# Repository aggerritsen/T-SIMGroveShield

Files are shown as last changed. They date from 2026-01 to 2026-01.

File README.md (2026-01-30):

# T-SIM Grove shield (ESP32 / ESP32-S3)

This repository contains a **clean, deterministic UART/I2C/GPIO baseline** used to validate reliable communication between **LilyGO T-SIM boards** and other boards using a generic T-SIM Grove Shield. This shield also provides a male header connector for the XIAO slot of the Seeed Grove Vision AI V2 board.

The focus of this development is **transport correctness**, not application logic.
It provides a proven foundation for later integration of camera frames, AI inference data, or other high-volume payloads and the pilot of actuators like relays, DC or stepper motors and other I2C perhiphials development board. 

This development includes a UART stub for testing, build on a XIAO ESP32-S3. This board can be used with the Grove Shield for XIAO, linking both shields with a Grove cable. 

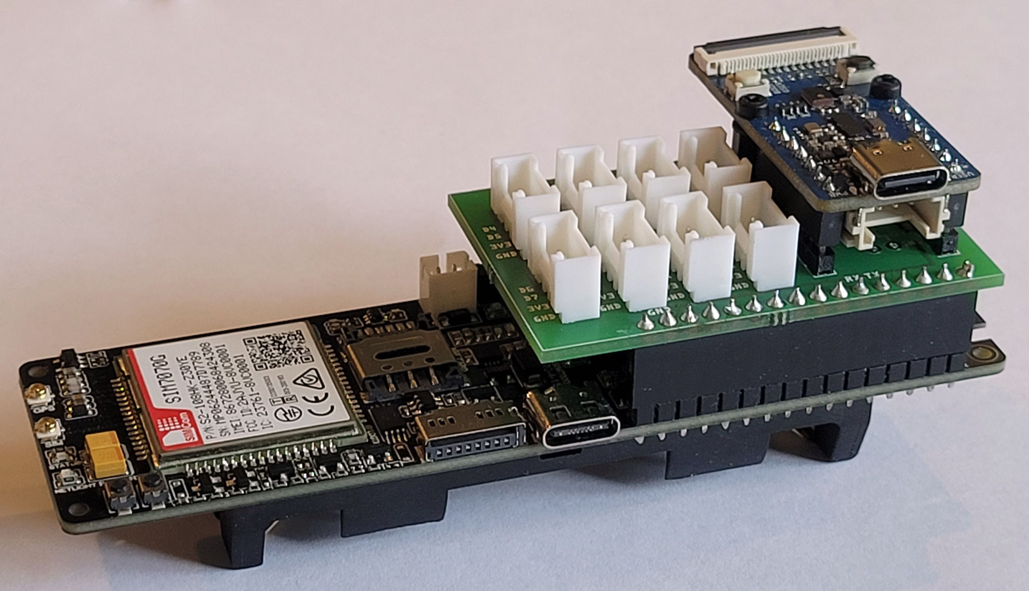
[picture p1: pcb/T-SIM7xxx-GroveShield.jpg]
PCB Grove Extension shield


## Printer Circuit Board (PCB)
A Fritzing file (fzz) is available to order the PCB at manufactors at choice.

Example shield:
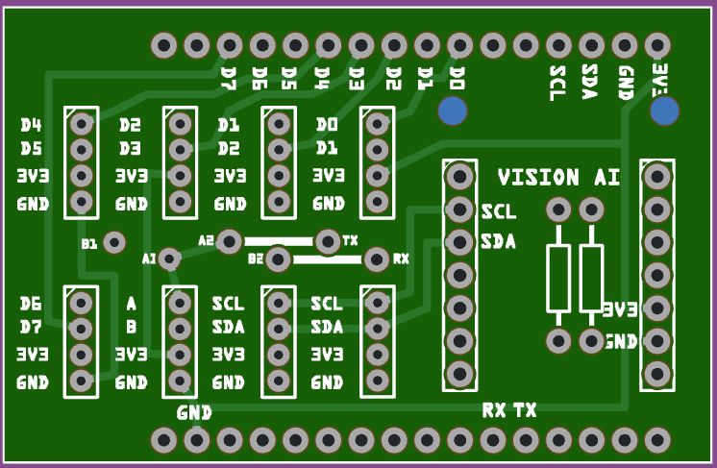
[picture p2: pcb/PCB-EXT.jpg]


## TX/RX wiring (Rev. B)
The TX and RX pins of UART Grove connector T-SIM Grove shield can be wired at choice with wire links.
| Config | Wires  | Pin 1 (A) | Pin 2 (B) |
|-----|-----|----|----|
|  1  | A1 -> TX, B1 -> RX | TX | RX |
|  2  | A2 -> RX, B2 -> TX | RX | TX | 

The wiring Pin1-TX, Pin2-RX (first configuration) is complementary to the cable wiring to the Grove Shield for XIAO (as shown in the picture) 

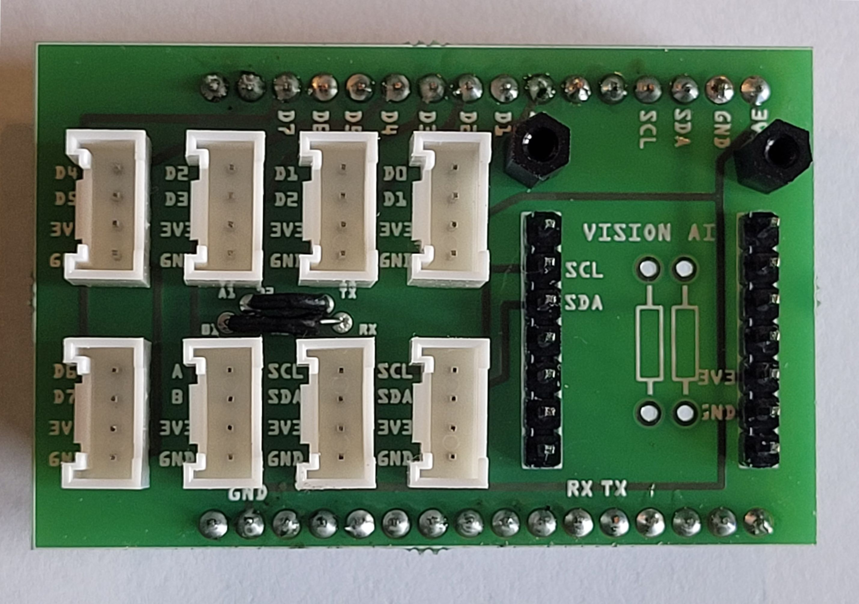
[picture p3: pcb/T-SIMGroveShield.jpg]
PCB Grove Extension shield


*The image shows earlier version with different UART wire bridges.*

---

## Goals of This Development

This project exists to answer these questions conclusively:

* Are pins wired correctly?
* Is high-speed UART stable (921600 baud) and I2C (400000 Hz)?
* Is the use of output GPIO consistent for all boards?
* Can we use generic shield (e.g. Grove, Relais, Motor driver) for all boards

---

* All boards use **HardwareSerial(1)** (UART1), leaving UART0 vor Serial communication
* All boards use **I2C-1 **, leaving I2C-0 for internal communication
* USB Serial is used **only for logging**
* The transport implementation is **identical across all boards**

---

## Supported Boards (current & verified)

| Board | MCU | Status |
| --- | --- | --- |
| XIAO ESP32-S3 | ESP32-S3 | ✅ Verified |
| T-SIM7080G-S3 | ESP32-S3 | ✅ Verified |
| T-SIM7070 | ESP32 | ✅ Verified |
| T-SIM7000G | ESP32 | ✅ Verified |
| T-SIM7600 | ESP32 / S3 | 🔜 Planned |
| T-SIM7670G | ESP32 / S3 | 🔜 Planned |

All verified boards are running **the same transport codebase**, differentiated only by PlatformIO environment configuration (pins, USB mode).

---

## Pin Configuration

### T-SIM7080G-S3 (ESP32-S3)

| Signal | GPIO | Notes |
| --- | --- | ----- |
| 3v3 | ------ | (P1.1) |
| GND | ------ | (P1.2) |
| SDA | GPIO16 | I2C-1 (P1.3) |
| SCL | GPIO17 | I2C-1 (P1.4) |
| TX  | GPIO43 | UART1 TX (P2.5)  |
| RX  | GPIO44 | UART1 RX (P2.6)  |
| D0 | GPIO03 | ----- |
| D1 | GPIO46 | *to be confirmed* |
| D2 | GPIO09 | ----- |
| D3 | GPIO10 | ----- |
| D4 | GPIO11 | ----- |
| D5 | GPIO12 | ----- |
| D6 | GPIO13 | ----- |
| D7 | GPIO14 | ----- |

### / T-SIM7000G / T-SIM7070 / T-SIM7600 / T-SIM7670G (ESP32 classic)

| Signal | GPIO | Notes |
| --- | --- | --- |
| 3v3 | ------ | (P1.1) |
| GND | ------ | (P1.2) |
| SDA | GPIO32 | I2C-1 (P1.3) |
| SCL | GPIO33 | I2C-1 (P1.4) |
| TX  | GPIO22 | UART1 TX (P2.5) |
| RX  | GPIO21 | UART1 RX (P2.6) |
| D0 | GPIO26 | ----- |
| D1 | GPIO25 | ----- |
| D2 | GPIO27 | ----- |
| D3 | GPIO04 | ----- |
| D4 | GPIO02 | ----- |
| D5 | GPIO15 | ----- |
| D6 | GPIO14 | ----- |
| D7 | GPIO13 | ----- |

**Important:**

* TX ↔ RX must be crossed
* GND must be shared
* Baud: 921600, 8N1 

---

## Architecture Overview for UART stub

```
+-------------------+        UART1 (921600 baud)        +---------------------+
| XIAO ESP32-S3     |  <----------------------------> | T-SIM (7080 / 7070 / |
| (Sender / Master) |                                  | 7000 Peer)          |
+-------------------+                                  +---------------------+
        |                                                             |
        | USB Serial (logs)                                           | USB Serial (logs)
        v                                                             v
   PlatformIO Monitor                                           PlatformIO Monitor
```

---

## Transport Protocol

The transport uses a **simple, explicit frame protocol**.

### Frame Format (wire-level)

```
FRAME <id> <len> <crc>
<payload>
END
```

### Fields

| Field | Meaning |
| --- | --- |
| `id` | Monotonic frame ID (uint32) |
| `len` | Exact payload length in bytes |
| `crc` | CRC32 (little-endian, hex) |
| `payload` | Message body |

The CRC is calculated **only over the payload**.

---

## Payload

In this baseline, the payload is **JSON text**, chosen for visibility:

```json
{
  "type": "sample",
  "frame": 7,
  "ts_ms": 16596,
  "msg": "Hello from XIAO UART1"
}
```

The transport is **payload-agnostic**. Binary data can replace JSON later without changing the protocol.

---

## CRC Handling

* Algorithm: **CRC32 little-endian**
* Implementation: `esp_crc32_le()` (ESP32 ROM)

A frame is rejected if:

* Payload length mismatches `len`
* Payload length exceeds safety limit
* CRC does not match

Rejected frames trigger a **NACK**.

---

## ACK / NACK Flow Control

### Normal flow

1. Sender transmits frame `N`
2. Receiver validates payload
3. Receiver replies:

```
ACK N
```

4. Sender advances to frame `N+1`

### Error flow

If validation fails:

```
NACK N
```

Sender resends **the same cached frame**.

### Timeout recovery

If no ACK or NACK is received within **5 seconds**:

* Sender automatically resends
* Frame ID does **not** advance

This guarantees reliable delivery over UART.

---

## Logging

Both sides produce **timestamped logs** on USB Serial:

```
[      9337] RX Frame id=5 OK: len=70 crc=2b685ad5
[      9337] TX ACK 5
```

Logging includes:

* RX header detection
* Payload capture
* CRC validation result
* ACK / NACK transmission
* Retry and timeout events

This makes transport behavior fully observable.

---

## PlatformIO Usage

### Upload (fixed COM port)

```ini
upload_port  = COM3
monitor_port = COM3
monitor_speed = 115200
```

### Build & upload

```bash
pio run -e t-sim7080g-s3 -t upload
```

### Monitor

```bash
pio device monitor
```

---

## What This Code Is (and Is Not)

### ✅ This is

* A transport validation harness
* A reliable UART framing baseline
* A reference implementation
* Safe to extend

### ❌ This is not

* A final production protocol
* Optimized for throughput
* Streaming-based
* Tied to AI, camera, or Grove logic

---

## Status

✅ **Transport proven stable across multiple devices**

This repository represents a known-good, cross-board UART communication foundation for:

* T-SIM7080G S3
* T-SIM7000G
* T-SIM7070G
* T-SIM7600
* T-SIM7670G S3

### UART stub for testing
* XIAO ESP32-S3

All devices have been validated at **921600 baud**, with correct CRC handling, ACK/NACK flow control, and automatic resend behavior.

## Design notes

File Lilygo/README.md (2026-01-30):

# T-SIM UART Peer Stub (UART1) + GPIO Walk + I2C-1 Incremental Scan

This Arduino/ESP32 sketch is a **UART “peer” stub** intended for **duplex testing** between a T-SIM7080G-S3 (ESP32-S3) and another device over **UART1**.

It implements a tiny, line-oriented framing protocol:

- Receives: `FRAME <id> <len> <crc32>` + **single-line payload** + `END`
- Validates:
  - payload length matches `<len>`
  - CRC32 matches `<crc32>` (computed with `esp_crc32_le`)
- Responds:
  - `ACK <id>` on success
  - `NACK <id>` on failure

In addition, the sketch can:

- Run a **non-blocking “walking 1” GPIO output test** across 8 pins (D0..D7)
- After each full GPIO cycle, start a **watchdog-safe incremental scan** of **I2C bus 1** (`TwoWire(1)`), probing **one address per loop**
- Provide **timestamped USB serial logs** (millis-based)

Serial output:

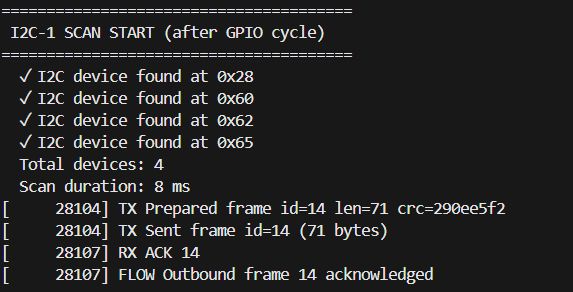
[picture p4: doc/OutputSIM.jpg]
Serial output SIM


---

## Features

### 1) UART1 peer stub (receive + validate + ACK/NACK)
- Uses `HardwareSerial(1)` with configurable baud and pins.
- Parses inbound frames from UART1, expecting:

```text
FRAME <id> <len> <crc32hex>
<payload line>
END
````

* Verifies:

  * `<len>` <= `MAX_PAYLOAD_LEN` (default 4096)
  * `payload.length() == <len>`
  * `CRC32(payload) == <crc32>`

* Replies on UART1:

```text
ACK <id>
```

or

```text
NACK <id>
```

### 2) Optional periodic outbound frames (duplex testing)

If enabled, this device will periodically transmit sample frames and wait for `ACK`/`NACK`:

* On `ACK <id>` matching the last sent frame → mark it acknowledged.
* On `NACK <id>` matching the last sent frame → **immediately resend**.
* On timeout (`ACK_TIMEOUT_MS`, default 5000 ms) → **resend**.

### 3) Non-blocking GPIO output “walking 1” test (D0..D7)

* Configures up to 8 GPIOs as outputs.
* Every `GPIO_TEST_INTERVAL_MS` (default 200 ms), sets exactly one pin HIGH and the others LOW.
* After completing a full cycle (wraps from D7 back to D0), it triggers an I2C scan start.

Pins are provided via build flags (`D0_GPIO_CFG`…`D7_GPIO_CFG`). Unset pins default to `-1` and are ignored.

### 4) Watchdog-safe I2C-1 scan (incremental)

* Uses **I2C bus 1**: `TwoWire(1)` (not bus 0).
* Initializes once with explicit SDA/SCL pins.
* After each GPIO full cycle, starts a scan from address `0x03` to `0x77`.
* **Scans one address per loop iteration** to stay watchdog safe.

---

## Hardware / Wiring

### UART1 (BrokerUART)

Defaults (can be overridden with build flags):

* Baud: `921600`
* TX GPIO: `18`  (T-SIM7080G-S3 TX)
* RX GPIO: `8`   (T-SIM7080G-S3 RX)

> Ensure **cross wiring** with the other device:
>
> * This device TX → other device RX
> * This device RX → other device TX
> * Common GND

### I2C bus 1

I2C-1 requires explicit pin configuration via build flags:

* `I2C1_SDA_GPIO_CFG`
* `I2C1_SCL_GPIO_CFG`

Optional:

* `I2C1_FREQ_CFG` (default 400 kHz)

### GPIO walk test

Define up to 8 output pins:

* `D0_GPIO_CFG` … `D7_GPIO_CFG`

Unset pins are skipped.

---

## Protocol details

### Frame header

A header line must start with `FRAME `:

```text
FRAME <id> <len> <crc>
```

* `<id>`: integer frame identifier
* `<len>`: payload length in bytes
* `<crc>`: CRC32 of the payload (hex), computed with `esp_crc32_le()`

### Payload

This stub expects a **single-line payload** (everything up to the next newline). The captured payload is validated against `<len>` and `<crc>`.

### Terminator

The line `END` completes the frame and triggers validation + ACK/NACK.

---

## Configuration (compile-time build flags)

All runtime behavior is controlled by compile-time macros (typically via PlatformIO `build_flags`).

### UART config

* `BROKER_UART_BAUD_CFG` (default 921600)
* `BROKER_UART_TX_GPIO_CFG` (default 18)
* `BROKER_UART_RX_GPIO_CFG` (default 8)

Enable/disable:

* `ENABLE_BROKER_UART_CFG` (default 1)
* `ENABLE_BROKER_PERIODIC_TX_CFG` (default 0)

### Protocol / flow

These are constants in the code:

* `ACK_TIMEOUT_MS` (default 5000)
* `TX_INTERVAL_MS` (default 2000)
* `MAX_PAYLOAD_LEN` (default 4096)

### GPIO walk test

* `ENABLE_GPIO_TEST_CFG` (default 1)
* `GPIO_TEST_INTERVAL_MS_CFG` (default 200)
* `D0_GPIO_CFG` … `D7_GPIO_CFG`

### I2C-1 scan

* `ENABLE_I2C_SCAN_CFG` (default 1)
* `I2C1_SDA_GPIO_CFG` (required to actually init)
* `I2C1_SCL_GPIO_CFG` (required to actually init)
* `I2C1_FREQ_CFG` (default 400000)

---

## Example PlatformIO configuration

```ini
; platformio.ini (example)
[env:tsim7080g]
platform = espressif32
board = esp32-s3-devkitc-1
framework = arduino
monitor_speed = 115200
build_flags =
  -DBROKER_UART_BAUD_CFG=921600
  -DBROKER_UART_TX_GPIO_CFG=18
  -DBROKER_UART_RX_GPIO_CFG=8
  -DENABLE_BROKER_UART_CFG=1
  -DENABLE_BROKER_PERIODIC_TX_CFG=0

  -DENABLE_GPIO_TEST_CFG=1
  -DGPIO_TEST_INTERVAL_MS_CFG=200
  -DD0_GPIO_CFG=9
  -DD1_GPIO_CFG=10
  -DD2_GPIO_CFG=11
  -DD3_GPIO_CFG=12
  -DD4_GPIO_CFG=13
  -DD5_GPIO_CFG=14
  -DD6_GPIO_CFG=21
  -DD7_GPIO_CFG=47

  -DENABLE_I2C_SCAN_CFG=1
  -DI2C1_SDA_GPIO_CFG=7
  -DI2C1_SCL_GPIO_CFG=6
  -DI2C1_FREQ_CFG=400000
```

> Notes:
>
> * Use the correct `board` for your actual PlatformIO environment.
> * If you don’t define I2C1 pins, the sketch will log that I2C-1 is not configured and skip scanning.

---

## What you should see in logs

### Boot

* Build timestamp
* UART1 config
* GPIO test configuration
* I2C-1 init status

### UART receive

* `Header FRAME ...`
* `Payload captured ...`
* `END for frame ...`
* `Frame ... OK` and an `ACK ...` **or** a rejection reason and `NACK ...`

### GPIO + I2C scan

* Every GPIO cycle wrap triggers an I2C scan start.
* Each loop scans one I2C address; discovered devices are printed as:

```text
✓ I2C device found at 0xXX
```

---

## Known limitations / assumptions

* Payload is currently treated as **single-line** (captured from one `readStringUntil('\n')`). Multi-line payloads are not supported in this stub.
* CRC is computed over the payload bytes exactly as received after trimming the line.
* Very high UART baud rates (like 921600) require good wiring/grounding and stable clocks on both ends.

---

## File overview

This program is a single sketch (no separate modules) and includes:

* UART framing + CRC validation
* Duplex ACK/NACK flow for optional periodic TX
* GPIO walking test (non-blocking)
* I2C bus 1 incremental scan (watchdog safe)

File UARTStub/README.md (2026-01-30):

# UART Stub Transport – XIAO ESP32-S3

This repository contains a **minimal, deterministic UART transport stub** intended for bring-up, wiring validation, and protocol testing between a **XIAO ESP32-S3** and a peer device (e.g. T-SIM board).

The implementation focuses on **reliability, observability, and simplicity**. It deliberately avoids application logic (AI, Grove, sensors) and instead provides a clean UART framing, CRC validation, ACK/NACK flow, and timestamped logging.

---

## Purpose

This stub exists to answer one question unambiguously:

> *Does my UART link work correctly under load, with retries and integrity checks?*

It is designed as a **transport sanity harness** that you can trust before layering higher-level protocols or large binary payloads (images, inference data, etc.) on top.

Serial output:

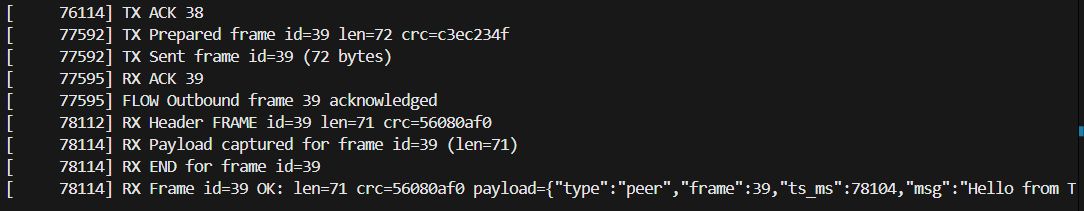
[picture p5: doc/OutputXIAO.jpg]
Serial Output XIAO


---

## Key Features

* Uses **second hardware UART** (`HardwareSerial(1)`) on ESP32-S3
* High-speed UART: **921600 baud**
* Explicit TX/RX pin mapping
* Application-level **frame protocol**
* **CRC32 (little-endian)** payload integrity check
* **ACK / NACK** flow control
* Automatic resend on timeout or NACK
* Timestamped USB serial logging (`millis()`)
* No external library dependencies

---

## UART Configuration

| Parameter | Value |
| --- | --- |
| UART instance | UART1 (`HardwareSerial(1)`) |
| Baud rate | 921600 |
| Data format | 8N1 |
| TX pin | GPIO 43 |
| RX pin | GPIO 44 |

> ⚠️ TX/RX **must be crossed** and **GND must be shared** with the peer device.

---

## Frame Protocol

All communication uses a simple, line-based application frame.

### Wire Format

```
FRAME <id> <len> <crc>
<payload>
END
```

### Fields

| Field | Description |
| --- | --- |
| `id` | Monotonically increasing frame ID (uint32) |
| `len` | Exact payload length in bytes |
| `crc` | CRC32 (hex, little-endian) of payload only |
| `payload` | Message body (JSON in this stub) |

The header and `END` marker are **not** included in the CRC calculation.

---

## Payload

In this development stub, the payload is a **small JSON message**:

```json
{
  "type": "sample",
  "frame": 1,
  "ts_ms": 12345,
  "msg": "Hello from XIAO UART1"
}
```

This is intentionally human-readable to simplify debugging. The protocol is payload-agnostic and can later be replaced with binary data without changing the transport logic.

---

## CRC Handling

* CRC algorithm: **CRC32 little-endian**
* Implementation: `esp_crc32_le()` from ESP32 ROM
* CRC is calculated over the **exact payload bytes**

### Validation rules

A received frame is rejected if:

* Payload length does not match header `len`
* Payload length exceeds safety limit
* Calculated CRC does not match header CRC

Rejected frames trigger a `NACK <id>`.

---

## ACK / NACK Flow

### Normal flow

1. Sender transmits a frame
2. Receiver validates length and CRC
3. Receiver replies:

```
ACK <id>
```

4. Sender clears its retry state and proceeds with next frame

### Error flow

If validation fails:

```
NACK <id>
```

The sender **resends the same cached frame** (ID does not advance).

### Timeout flow

If no ACK/NACK is received within **5 seconds**:

* Sender automatically resends the cached frame
* Retries continue until ACK is received

This guarantees idempotent, loss-tolerant delivery.

---

## Logging

All events are logged to USB Serial (`Serial`) with timestamps:

```
[      1692] TX Prepared frame id=1 len=70 crc=6f60a379
[      1692] TX Sent frame id=1 (70 bytes)
[      6693] FLOW ACK timeout for frame 1 → resend
```

This makes timing, retries, and protocol state immediately visible during development.

---

## Dependencies

**None beyond the ESP32 Arduino core.**

Used headers:

* `<Arduino.h>`
* `"esp_crc.h"`

No Grove, AI, Wire, RTOS, or external libraries are required.

---

## Intended Use

This stub is ideal for:

* UART wiring validation
* High-baud stability testing
* RX/TX pin verification
* CRC and framing validation
* Developing the peer receiver firmware
* Debugging transport issues in isolation

It is **not** intended as a final production protocol.

---

## Next Steps

Once this stub is proven stable, you can safely:

* Replace JSON payloads with binary data
* Add multi-chunk payload support
* Integrate camera or AI outputs
* Add protocol versioning
* Move from line-based to length-based RX

The transport layer can remain unchanged.

---

## Status

✅ Transport verified

This code represents a known-good UART transport baseline.

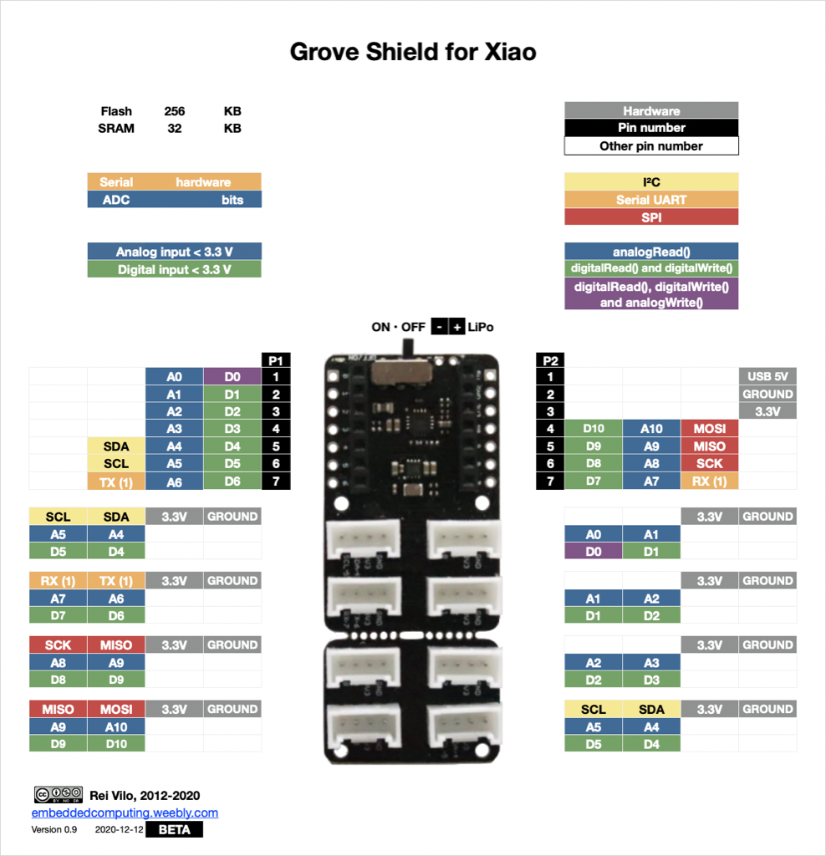
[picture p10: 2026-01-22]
doc/xiao-grove-shield-for-xiao_orig.png

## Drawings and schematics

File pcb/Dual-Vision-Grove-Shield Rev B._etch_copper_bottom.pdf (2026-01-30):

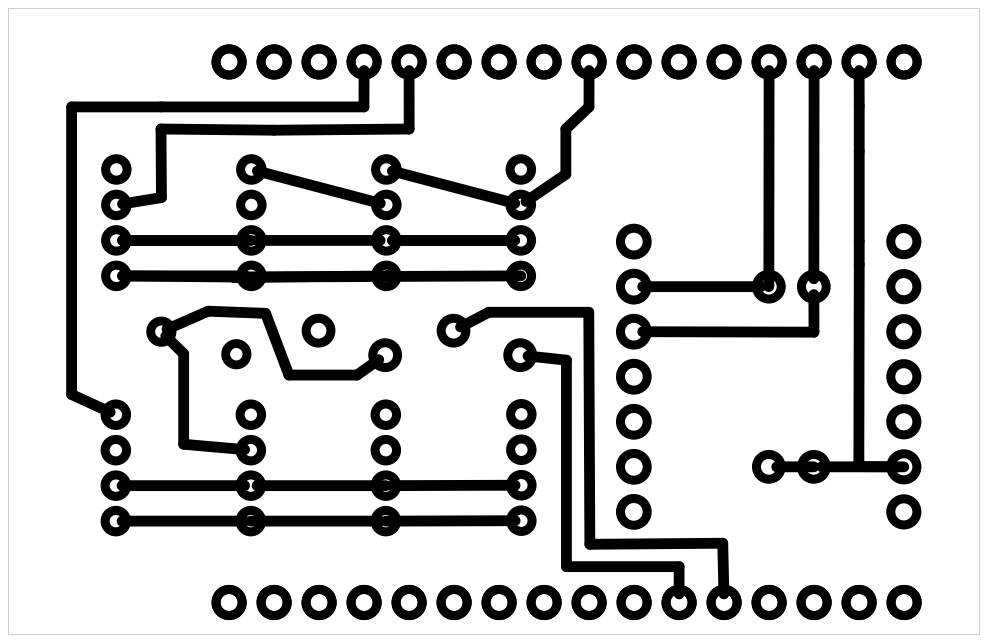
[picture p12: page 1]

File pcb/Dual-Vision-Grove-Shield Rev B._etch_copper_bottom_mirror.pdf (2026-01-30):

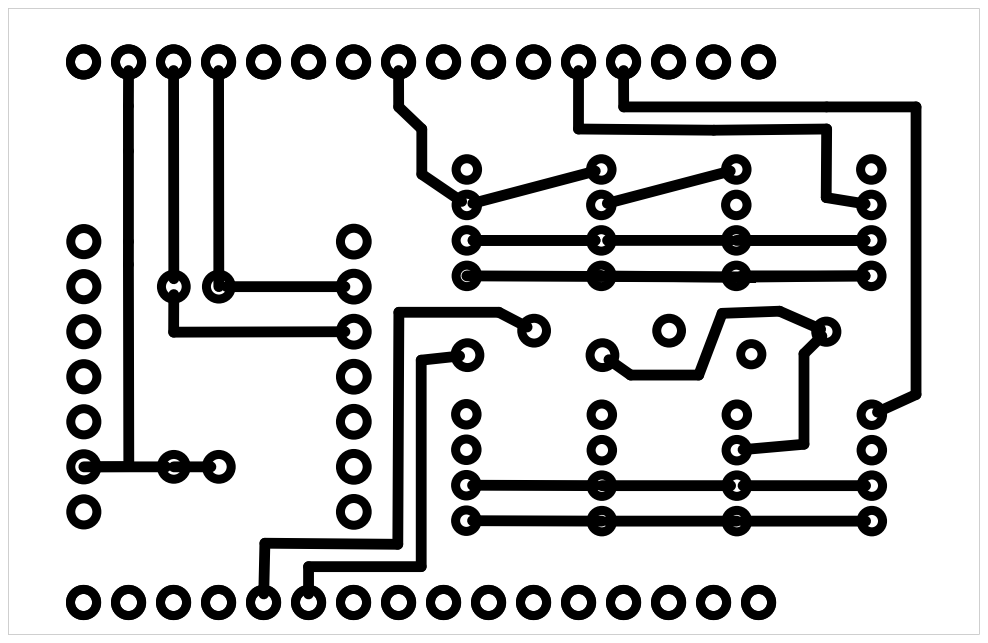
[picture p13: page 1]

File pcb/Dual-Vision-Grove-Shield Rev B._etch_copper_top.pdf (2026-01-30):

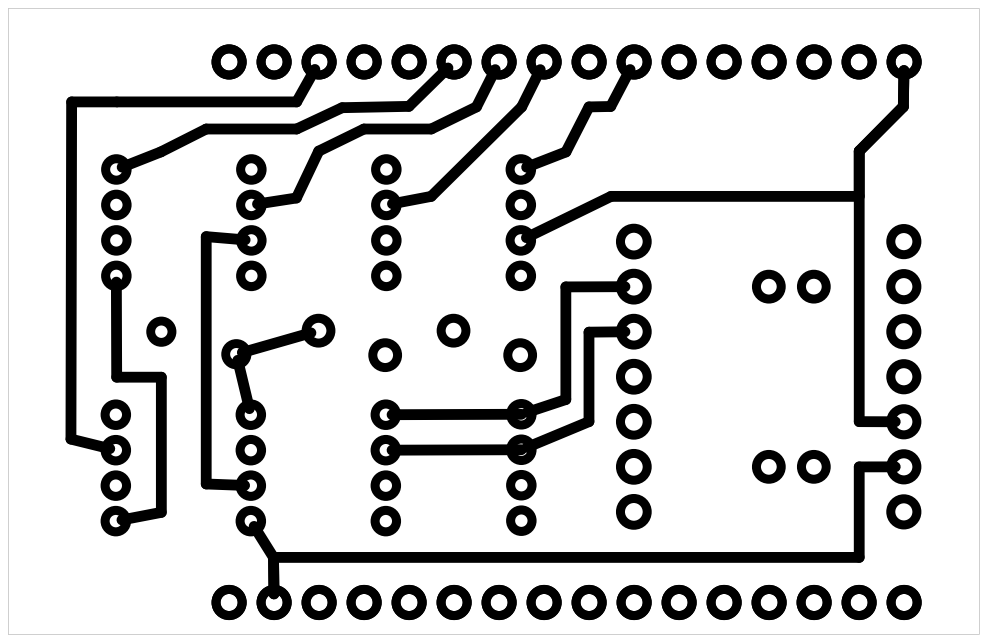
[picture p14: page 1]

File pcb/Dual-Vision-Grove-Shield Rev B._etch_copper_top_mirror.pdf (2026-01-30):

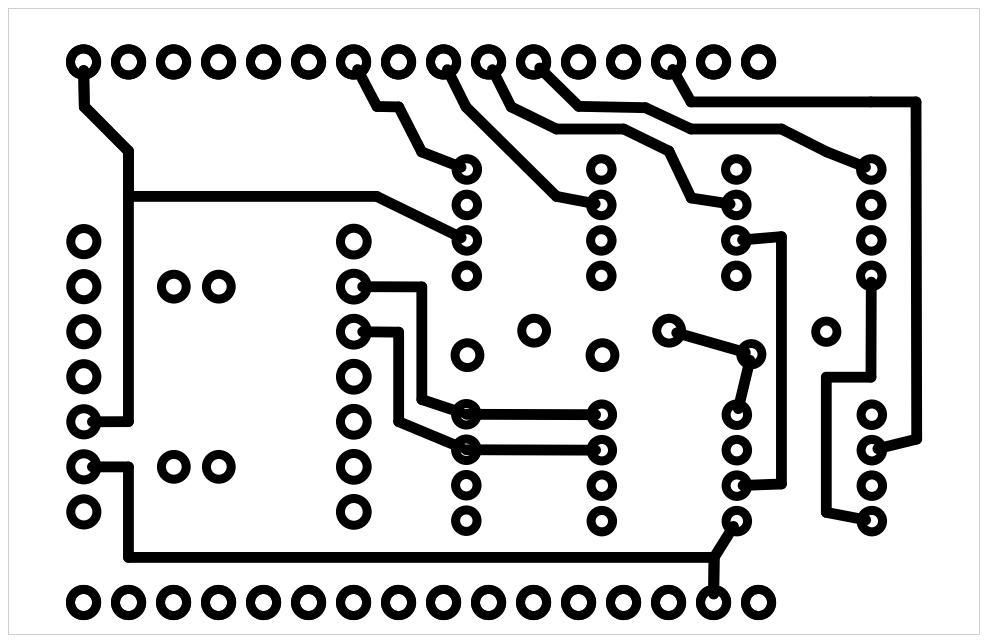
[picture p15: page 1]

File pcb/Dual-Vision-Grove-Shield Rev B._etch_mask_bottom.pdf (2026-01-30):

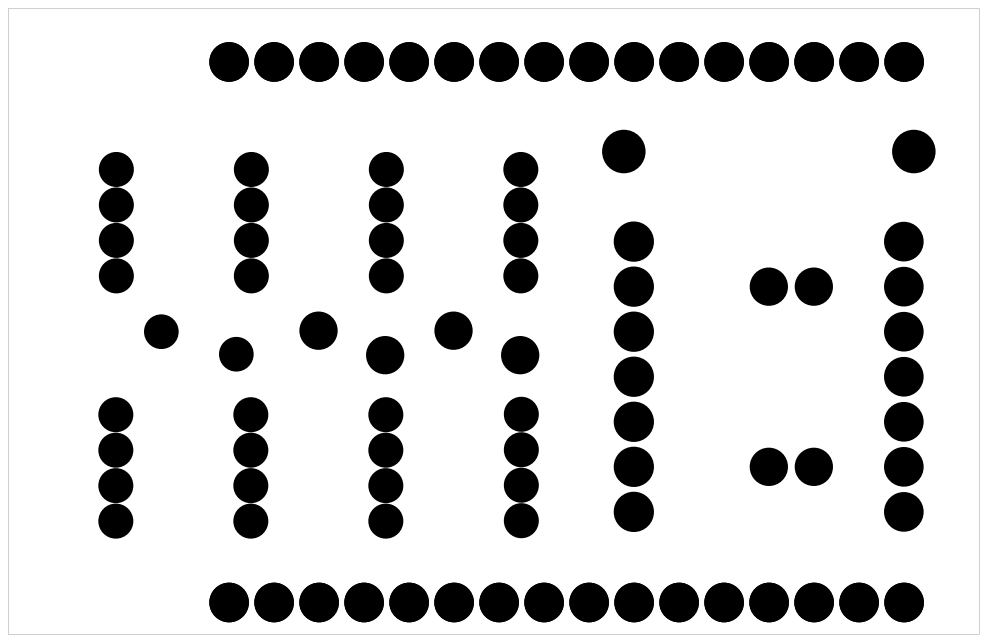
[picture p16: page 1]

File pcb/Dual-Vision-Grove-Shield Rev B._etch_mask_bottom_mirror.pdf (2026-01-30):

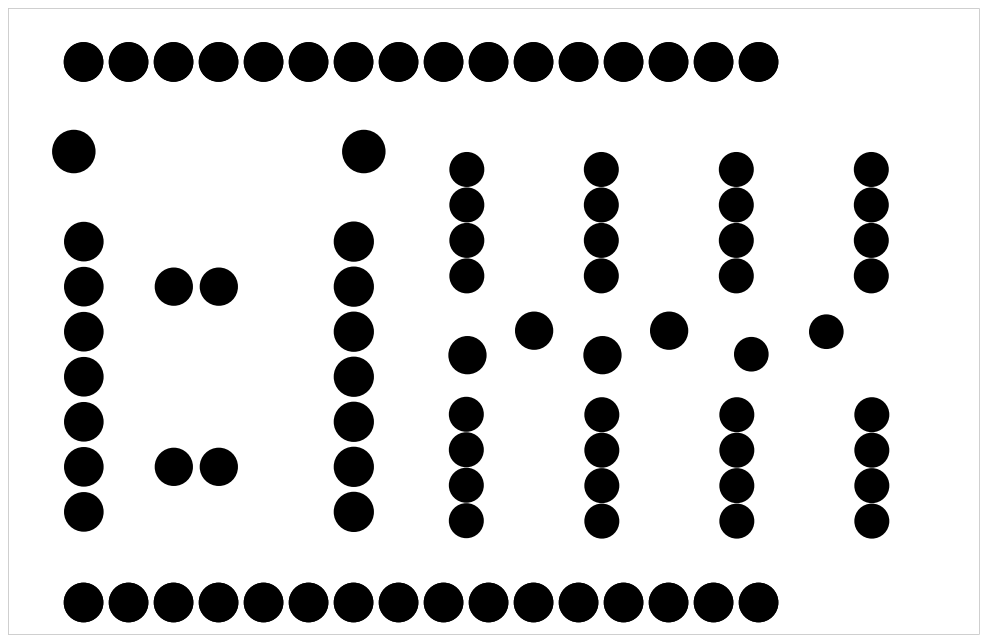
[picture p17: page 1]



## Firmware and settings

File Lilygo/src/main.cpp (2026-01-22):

#include <Arduino.h>
#include <Wire.h>
#include "esp_crc.h"

/* =========================================================
   UART PEER STUB (T-SIM7080G-S3 | UART1)
   - Uses HardwareSerial(1)
   - Receives FRAME/LEN/CRC + payload + END
   - Validates length + CRC32 (esp_crc32_le)
   - Responds ACK <id> or NACK <id>
   - Optional periodic TX sample frames (duplex testing)
   - Timestamped USB serial logging (millis)
   ========================================================= */

/* ================================
   BROKER UART CONFIG (defaults; overridable via build_flags *_CFG)
   Use non-generic names to avoid collisions with Arduino core macros.
   ================================ */
static constexpr uint32_t BROKER_UART_BAUD_DEFAULT     = 921600;
static constexpr int      BROKER_UART_TX_GPIO_DEFAULT  = 18; // T-SIM7080G-S3 TX (P1.5) GPIO18
static constexpr int      BROKER_UART_RX_GPIO_DEFAULT  = 8;  // T-SIM7080G-S3 RX (P1.6) GPIO08

static constexpr bool     ENABLE_BROKER_UART_DEFAULT        = true;
static constexpr bool     ENABLE_BROKER_PERIODIC_TX_DEFAULT = false;

/* Resolve final config (compile-time) */
#ifdef BROKER_UART_BAUD_CFG
static constexpr uint32_t BROKER_UART_BAUD = (uint32_t)BROKER_UART_BAUD_CFG;
#else
static constexpr uint32_t BROKER_UART_BAUD = BROKER_UART_BAUD_DEFAULT;
#endif

#ifdef BROKER_UART_TX_GPIO_CFG
static constexpr int BROKER_UART_TX_GPIO = (int)BROKER_UART_TX_GPIO_CFG;
#else
static constexpr int BROKER_UART_TX_GPIO = BROKER_UART_TX_GPIO_DEFAULT;
#endif

#ifdef BROKER_UART_RX_GPIO_CFG
static constexpr int BROKER_UART_RX_GPIO = (int)BROKER_UART_RX_GPIO_CFG;
#else
static constexpr int BROKER_UART_RX_GPIO = BROKER_UART_RX_GPIO_DEFAULT;
#endif

#ifdef ENABLE_BROKER_UART_CFG
static constexpr bool ENABLE_BROKER_UART = (ENABLE_BROKER_UART_CFG != 0);
#else
static constexpr bool ENABLE_BROKER_UART = ENABLE_BROKER_UART_DEFAULT;
#endif

#ifdef ENABLE_BROKER_PERIODIC_TX_CFG
static constexpr bool ENABLE_BROKER_PERIODIC_TX = (ENABLE_BROKER_PERIODIC_TX_CFG != 0);
#else
static constexpr bool ENABLE_BROKER_PERIODIC_TX = ENABLE_BROKER_PERIODIC_TX_DEFAULT;
#endif

/* ================================
   GPIO OUTPUT TEST (D0..D7)
   - Non-blocking "walking 1" pattern: one pin HIGH at a time, sequential, perpetual
   - Purely additive: does not alter UART/protocol logic
   - Pins are set via build_flags: D0_GPIO_CFG..D7_GPIO_CFG
   ================================ */
static constexpr bool     ENABLE_GPIO_TEST_DEFAULT        = true;
static constexpr uint32_t GPIO_TEST_INTERVAL_MS_DEFAULT   = 200;

#ifdef ENABLE_GPIO_TEST_CFG
static constexpr bool ENABLE_GPIO_TEST = (ENABLE_GPIO_TEST_CFG != 0);
#else
static constexpr bool ENABLE_GPIO_TEST = ENABLE_GPIO_TEST_DEFAULT;
#endif

#ifdef GPIO_TEST_INTERVAL_MS_CFG
static constexpr uint32_t GPIO_TEST_INTERVAL_MS = (uint32_t)GPIO_TEST_INTERVAL_MS_CFG;
#else
static constexpr uint32_t GPIO_TEST_INTERVAL_MS = GPIO_TEST_INTERVAL_MS_DEFAULT;
#endif

// Defaults are placeholders; final values should come from build_flags per env.
#ifdef D0_GPIO_CFG
static constexpr int D0_GPIO = (int)D0_GPIO_CFG;
#else
static constexpr int D0_GPIO = -1;
#endif

#ifdef D1_GPIO_CFG
static constexpr int D1_GPIO = (int)D1_GPIO_CFG;
#else
static constexpr int D1_GPIO = -1;
#endif

#ifdef D2_GPIO_CFG
static constexpr int D2_GPIO = (int)D2_GPIO_CFG;
#else
static constexpr int D2_GPIO = -1;
#endif

#ifdef D3_GPIO_CFG
static constexpr int D3_GPIO = (int)D3_GPIO_CFG;
#else
static constexpr int D3_GPIO = -1;
#endif

#ifdef D4_GPIO_CFG
static constexpr int D4_GPIO = (int)D4_GPIO_CFG;
#else
static constexpr int D4_GPIO = -1;
#endif

#ifdef D5_GPIO_CFG
static constexpr int D5_GPIO = (int)D5_GPIO_CFG;
#else
static constexpr int D5_GPIO = -1;
#endif

#ifdef D6_GPIO_CFG
static constexpr int D6_GPIO = (int)D6_GPIO_CFG;
#else
static constexpr int D6_GPIO = -1;
#endif

#ifdef D7_GPIO_CFG
static constexpr int D7_GPIO = (int)D7_GPIO_CFG;
#else
static constexpr int D7_GPIO = -1;
#endif

static const int GPIO_TEST_PINS[8] = {
  D0_GPIO, D1_GPIO, D2_GPIO, D3_GPIO, D4_GPIO, D5_GPIO, D6_GPIO, D7_GPIO
};

static uint32_t gpio_next_step_ms = 0;
static uint8_t  gpio_step_index   = 0;

static inline void gpio_write_safe(int pin, uint8_t level)
{
  if (pin < 0) return;
  digitalWrite(pin, level);
}

/* ================================
   I2C-1 SCAN (AFTER EACH GPIO CYCLE) - WATCHDOG SAFE
   - Must scan bus 1 (not bus 0)
   - Uses TwoWire(1)
   - Bus initialized once
   - Scan runs incrementally: 1 address per loop tick (no blocking)
   ================================ */
static constexpr bool     ENABLE_I2C_SCAN_DEFAULT = true;

#ifdef ENABLE_I2C_SCAN_CFG
static constexpr bool ENABLE_I2C_SCAN = (ENABLE_I2C_SCAN_CFG != 0);
#else
static constexpr bool ENABLE_I2C_SCAN = ENABLE_I2C_SCAN_DEFAULT;
#endif

#ifdef I2C1_SDA_GPIO_CFG
static constexpr int I2C1_SDA_GPIO = (int)I2C1_SDA_GPIO_CFG;
#else
static constexpr int I2C1_SDA_GPIO = -1;
#endif

#ifdef I2C1_SCL_GPIO_CFG
static constexpr int I2C1_SCL_GPIO = (int)I2C1_SCL_GPIO_CFG;
#else
static constexpr int I2C1_SCL_GPIO = -1;
#endif

#ifdef I2C1_FREQ_CFG
static constexpr uint32_t I2C1_FREQ = (uint32_t)I2C1_FREQ_CFG;
#else
static constexpr uint32_t I2C1_FREQ = 400000;
#endif

TwoWire I2Cbus1 = TwoWire(1);
static bool i2c1_initialized = false;

// incremental scan state
static bool     i2c_scan_active = false;
static uint8_t  i2c_scan_addr   = 0x03;
static uint8_t  i2c_scan_found  = 0;
static uint32_t i2c_scan_start_ms = 0;

static void i2c1_init_once()
{
  if (!ENABLE_I2C_SCAN) return;
  if (i2c1_initialized) return;

  if (I2C1_SDA_GPIO < 0 || I2C1_SCL_GPIO < 0)
  {
    Serial.println("[I2C] I2C-1 pins not configured (I2C1_SDA_GPIO_CFG / I2C1_SCL_GPIO_CFG)");
    return;
  }

  Serial.println("=======================================");
  Serial.println(" I2C-1 INIT (external bus)");
  Serial.println("=======================================");
  Serial.printf(" SDA=%d SCL=%d freq=%lu Hz\n",
                I2C1_SDA_GPIO, I2C1_SCL_GPIO, (unsigned long)I2C1_FREQ);

  // Initialize I2C bus 1 with explicit pins
  I2Cbus1.begin(I2C1_SDA_GPIO, I2C1_SCL_GPIO, I2C1_FREQ);

  i2c1_initialized = true;
}

static void i2c1_scan_start()
{
  if (!ENABLE_I2C_SCAN) return;
  if (!i2c1_initialized) return;

  // start a new scan
  i2c_scan_active = true;
  i2c_scan_addr = 0x03;
  i2c_scan_found = 0;
  i2c_scan_start_ms = millis();

  Serial.println("=======================================");
  Serial.println(" I2C-1 SCAN START (after GPIO cycle)");
  Serial.println("=======================================");
}

static void i2c1_scan_tick()
{
  if (!ENABLE_I2C_SCAN) return;
  if (!i2c1_initialized) return;
  if (!i2c_scan_active) return;

  // Scan exactly ONE address per loop iteration (watchdog safe)
  const uint8_t addr = i2c_scan_addr;

  I2Cbus1.beginTransmission(addr);
  if (I2Cbus1.endTransmission() == 0)
  {
    Serial.printf("  ✓ I2C device found at 0x%02X\n", addr);
    i2c_scan_found++;
  }

  // advance
  if (i2c_scan_addr >= 0x77)
  {
    const uint32_t dur = millis() - i2c_scan_start_ms;

    if (i2c_scan_found == 0)
      Serial.println("  (no I2C devices found)");
    else
      Serial.printf("  Total devices: %u\n", i2c_scan_found);

    Serial.printf("  Scan duration: %lu ms\n", (unsigned long)dur);

    i2c_scan_active = false;
    return;
  }

  i2c_scan_addr++;

  // Give FreeRTOS/USB time; avoids WDT even on busy systems.
  delay(0);
}

/* ================================
   GPIO test init/tick
   ================================ */
static void gpio_test_init()
{
  if (!ENABLE_GPIO_TEST) return;

  // Configure pins as outputs, set LOW
  for (int i = 0; i < 8; i++)
  {
    const int pin = GPIO_TEST_PINS[i];
    if (pin >= 0)
    {
      pinMode(pin, OUTPUT);
      digitalWrite(pin, LOW);
    }
  }

  gpio_step_index = 0;
  gpio_next_step_ms = millis() + GPIO_TEST_INTERVAL_MS;
}

static void gpio_test_tick()
{
  if (!ENABLE_GPIO_TEST) return;

  const uint32_t now = millis();
  if ((int32_t)(now - gpio_next_step_ms) < 0) return;

  // Walking 1: all LOW except the active index HIGH
  for (int i = 0; i < 8; i++)
  {
    gpio_write_safe(GPIO_TEST_PINS[i], (i == gpio_step_index) ? HIGH : LOW);
  }

  // Advance and detect wrap (end of cycle)
  gpio_step_index = (uint8_t)((gpio_step_index + 1) & 0x07);

  // After each full D0..D7 cycle (wrap back to 0), start I2C-1 scan
  if (gpio_step_index == 0)
  {
    i2c1_scan_start();
  }

  gpio_next_step_ms = now + GPIO_TEST_INTERVAL_MS;
}

/* ================================
   PROTOCOL / FLOW
   ================================ */
static constexpr uint32_t ACK_TIMEOUT_MS  = 5000;
static constexpr uint32_t TX_INTERVAL_MS  = 2000;
static constexpr uint32_t MAX_PAYLOAD_LEN = 4096;

/* ================================
   UART
   ================================ */
HardwareSerial BrokerUART(1);

/* ================================
   STATE (outbound)
   ================================ */
static uint32_t tx_frame_id     = 0;
static bool     awaiting_ack    = false;
static uint32_t last_send_ms    = 0;
static uint32_t next_tx_ms      = 0;
static String   cached_payload;
static uint32_t cached_crc      = 0;

/* ================================
   STATE (inbound parser)
   ================================ */
static bool     rx_in_frame     = false;
static uint32_t rx_id           = 0;
static size_t   rx_len          = 0;
static uint32_t rx_crc          = 0;
static String   rx_payload;

/* ================================
   LOGGING (timestamps)
   ================================ */
static inline void log_ts(const char* tag, const char* fmt, ...)
{
  char buf[256];
  va_list ap;
  va_start(ap, fmt);
  vsnprintf(buf, sizeof(buf), fmt, ap);
  va_end(ap);

  Serial.printf("[%10lu] %s %s\n", (unsigned long)millis(), tag, buf);
}

/* ================================
   CRC32 helper (LE)
   ================================ */
static inline uint32_t crc32_of_string(const String& s)
{
  return esp_crc32_le(0, (const uint8_t*)s.c_str(), s.length());
}

/* ================================
   TX: ACK / NACK
   ================================ */
static void send_ack(uint32_t id)
{
  if (!ENABLE_BROKER_UART) return;
  BrokerUART.print("ACK ");
  BrokerUART.println(id);
  log_ts("TX", "ACK %lu", (unsigned long)id);
}

static void send_nack(uint32_t id)
{
  if (!ENABLE_BROKER_UART) return;
  BrokerUART.print("NACK ");
  BrokerUART.println(id);
  log_ts("TX", "NACK %lu", (unsigned long)id);
}

/* ================================
   TX: sample outbound frame (optional duplex)
   ================================ */
static void prepare_sample_frame()
{
  tx_frame_id++;

  cached_payload = "";
  cached_payload += "{\"type\":\"peer\",\"frame\":";
  cached_payload += tx_frame_id;
  cached_payload += ",\"ts_ms\":";
  cached_payload += (uint32_t)millis();
  cached_payload += ",\"msg\":\"Hello from T-SIM UART1\"}";

  cached_crc = crc32_of_string(cached_payload);

  log_ts("TX", "Prepared frame id=%lu len=%u crc=%08lx",
         (unsigned long)tx_frame_id,
         (unsigned)cached_payload.length(),
         (unsigned long)cached_crc);
}

static void send_cached_frame()
{
  if (!ENABLE_BROKER_UART) return;

  const size_t len = cached_payload.length();

  BrokerUART.print("FRAME ");
  BrokerUART.print(tx_frame_id);
  BrokerUART.print(" ");
  BrokerUART.print(len);
  BrokerUART.print(" ");
  BrokerUART.printf("%08lx\n", (unsigned long)cached_crc);

  BrokerUART.print(cached_payload);
  BrokerUART.print("\n");

  BrokerUART.println("END");

  last_send_ms = millis();
  awaiting_ack = true;

  log_ts("TX", "Sent frame id=%lu (%u bytes)", (unsigned long)tx_frame_id, (unsigned)len);
}

/* ================================
   RX: parse header
   ================================ */
static bool parse_frame_header(const String& line, uint32_t& out_id, size_t& out_len, uint32_t& out_crc)
{
  if (!line.startsWith("FRAME ")) return false;

  int p1 = line.indexOf(' ');
  if (p1 < 0) return false;
  int p2 = line.indexOf(' ', p1 + 1);
  if (p2 < 0) return false;
  int p3 = line.indexOf(' ', p2 + 1);
  if (p3 < 0) return false;

  String sid  = line.substring(p1 + 1, p2);
  String slen = line.substring(p2 + 1, p3);
  String scrc = line.substring(p3 + 1);

  sid.trim(); slen.trim(); scrc.trim();
  if (sid.isEmpty() || slen.isEmpty() || scrc.isEmpty()) return false;

  out_id  = (uint32_t)sid.toInt();
  out_len = (size_t)slen.toInt();

  char* endptr = nullptr;
  out_crc = (uint32_t)strtoul(scrc.c_str(), &endptr, 16);
  if (endptr == scrc.c_str()) return false;

  return true;
}

/* ================================
   RX: validate + respond
   ================================ */
static void handle_complete_rx_frame()
{
  if (rx_len > MAX_PAYLOAD_LEN)
  {
    log_ts("RX", "Frame id=%lu rejected: len=%u > MAX=%u",
           (unsigned long)rx_id, (unsigned)rx_len, (unsigned)MAX_PAYLOAD_LEN);
    send_nack(rx_id);
    return;
  }

  if (rx_payload.length() != rx_len)
  {
    log_ts("RX", "Frame id=%lu length mismatch: header=%u actual=%u",
           (unsigned long)rx_id, (unsigned)rx_len, (unsigned)rx_payload.length());
    send_nack(rx_id);
    return;
  }

  uint32_t calc = crc32_of_string(rx_payload);
  if (calc != rx_crc)
  {
    log_ts("RX", "Frame id=%lu CRC FAIL: rx=%08lx calc=%08lx",
           (unsigned long)rx_id, (unsigned long)rx_crc, (unsigned long)calc);
    send_nack(rx_id);
    return;
  }

  log_ts("RX", "Frame id=%lu OK: len=%u crc=%08lx payload=%s",
         (unsigned long)rx_id,
         (unsigned)rx_len,
         (unsigned long)rx_crc,
         rx_payload.c_str());

  send_ack(rx_id);
}

/* ================================
   RX: poll UART and process lines
   ================================ */
static void poll_uart_rx()
{
  if (!ENABLE_BROKER_UART) return;

  while (BrokerUART.available())
  {
    String line = BrokerUART.readStringUntil('\n');
    line.trim();
    if (line.isEmpty()) continue;

    // ACK/NACK for our outbound frames (if periodic TX enabled)
    if (line.startsWith("ACK "))
    {
      uint32_t ack_id = (uint32_t)line.substring(4).toInt();
      log_ts("RX", "ACK %lu", (unsigned long)ack_id);

      if (awaiting_ack && ack_id == tx_frame_id)
      {
        awaiting_ack = false;
        log_ts("FLOW", "Outbound frame %lu acknowledged", (unsigned long)ack_id);
      }
      continue;
    }

    if (line.startsWith("NACK "))
    {
      uint32_t nack_id = (uint32_t)line.substring(5).toInt();
      log_ts("RX", "NACK %lu", (unsigned long)nack_id);

      if (awaiting_ack && nack_id == tx_frame_id)
      {
        log_ts("FLOW", "Outbound frame %lu NACKed → resend", (unsigned long)nack_id);
        send_cached_frame();
      }
      continue;
    }

    // Inbound frame parsing
    if (!rx_in_frame)
    {
      uint32_t id = 0;
      size_t len = 0;
      uint32_t crc = 0;

      if (parse_frame_header(line, id, len, crc))
      {
        rx_in_frame = true;
        rx_id = id;
        rx_len = len;
        rx_crc = crc;
        rx_payload = "";

        log_ts("RX", "Header FRAME id=%lu len=%u crc=%08lx",
               (unsigned long)rx_id, (unsigned)rx_len, (unsigned long)rx_crc);
      }
      else
      {
        log_ts("RX", "Unrecognized line: %s", line.c_str());
      }
      continue;
    }
    else
    {
      if (line == "END")
      {
        log_ts("RX", "END for frame id=%lu", (unsigned long)rx_id);
        handle_complete_rx_frame();

        rx_in_frame = false;
        rx_id = 0;
        rx_len = 0;
        rx_crc = 0;
        rx_payload = "";
      }
      else
      {
        // single-line payload in this stub
        rx_payload = line;
        log_ts("RX", "Payload captured for frame id=%lu (len=%u)",
               (unsigned long)rx_id, (unsigned)rx_payload.length());
      }
    }
  }
}

/* ================================
   SETUP
   ================================ */
void setup()
{
  Serial.begin(115200);
  delay(500);

  Serial.println("=======================================");
  Serial.println(" T-SIM | UART PEER STUB (UART1) ");
  Serial.println("=======================================");
  log_ts("BOOT", "Build: %s %s", __DATE__, __TIME__);
  log_ts("BOOT", "UART1 TX=%d RX=%d baud=%lu",
         BROKER_UART_TX_GPIO, BROKER_UART_RX_GPIO, (unsigned long)BROKER_UART_BAUD);

  if (ENABLE_BROKER_UART)
  {
    BrokerUART.begin(BROKER_UART_BAUD, SERIAL_8N1, BROKER_UART_RX_GPIO, BROKER_UART_TX_GPIO);
    log_ts("BOOT", "UART transport enabled");
  }
  else
  {
    log_ts("BOOT", "UART transport DISABLED");
  }

  // GPIO test init (additive)
  if (ENABLE_GPIO_TEST)
  {
    log_ts("GPIO", "GPIO test enabled interval=%lu ms", (unsigned long)GPIO_TEST_INTERVAL_MS);
    log_ts("GPIO", "D0=%d D1=%d D2=%d D3=%d D4=%d D5=%d D6=%d D7=%d",
           D0_GPIO, D1_GPIO, D2_GPIO, D3_GPIO, D4_GPIO, D5_GPIO, D6_GPIO, D7_GPIO);
  }
  else
  {
    log_ts("GPIO", "GPIO test DISABLED");
  }
  gpio_test_init();

  // I2C-1 init once (scan runs incrementally after each GPIO cycle)
  if (ENABLE_I2C_SCAN)
  {
    log_ts("I2C", "I2C-1 scan enabled (after each GPIO cycle)");
  }
  else
  {
    log_ts("I2C", "I2C-1 scan DISABLED");
  }
  i2c1_init_once();

  next_tx_ms = millis() + 1500;
}

/* ================================
   LOOP
   ================================ */
void loop()
{
  // GPIO test tick (additive; non-blocking; triggers I2C scan start on wrap)
  gpio_test_tick();

  // I2C scan tick (non-blocking; one address per loop)
  i2c1_scan_tick();

  poll_uart_rx();

  if (!ENABLE_BROKER_UART) return;

  // Outbound timeout handling (only relevant if this side transmits)
  if (awaiting_ack)
  {
    if (millis() - last_send_ms > ACK_TIMEOUT_MS)
    {
      log_ts("FLOW", "ACK timeout for frame %lu → resend", (unsigned long)tx_frame_id);
      send_cached_frame();
      return;
    }
  }

  // Optional periodic TX to test duplex
  if (ENABLE_BROKER_PERIODIC_TX && !awaiting_ack)
  {
    const uint32_t now = millis();
    if ((int32_t)(now - next_tx_ms) >= 0)
    {
      prepare_sample_frame();
      send_cached_frame();
      next_tx_ms = now + TX_INTERVAL_MS;
    }
  }
}
